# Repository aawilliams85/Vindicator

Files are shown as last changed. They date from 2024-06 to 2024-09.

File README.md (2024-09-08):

SteamVR Saber Staff based on Tundra Labs sample project here: https://github.com/tundra-labs/rp2040_examples
Vanquisher Assembled 2
Vanquisher Parts
Vanquisher Assembled

## Structure
The subfolders in the main directory are as follows:
* VindicatorDriver
    * This contains the driver that tells SteamVR how to use the controller.
    * The subfolder "vindicator" should be copied to "C:\Program Files (x86)\Steam\steamapps\common\SteamVR\drivers"
* VindicatorFirmware
    * This is the RP2040 Arduino code that is programmed into the dev board
* VindicatorInputPCB
    * This is the KiCAD design for the button input board that connects to the RP2040 dev board.
* VindicatorJson
    * This contains example before and after device JSON files to show how to convert to/from the stock Tundra Tracker configuration. 
* VindicatorMechanical
    * This is the FreeCAD model for the 3D printed parts.

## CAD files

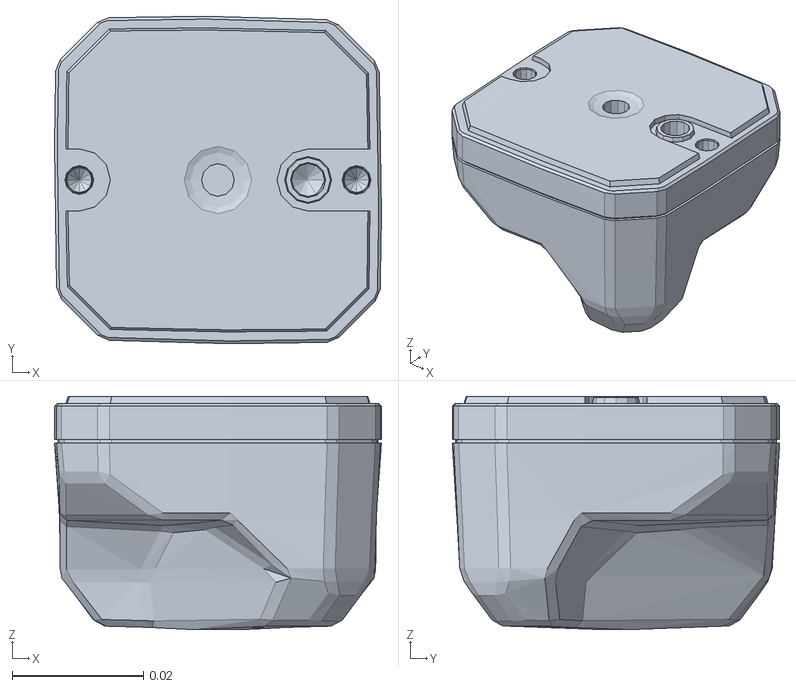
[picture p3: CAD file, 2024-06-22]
VindicatorDriver/vindicator/resources/rendermodels/vindicator/vindicator.obj
0.0499 x 0.05 x 0.0356

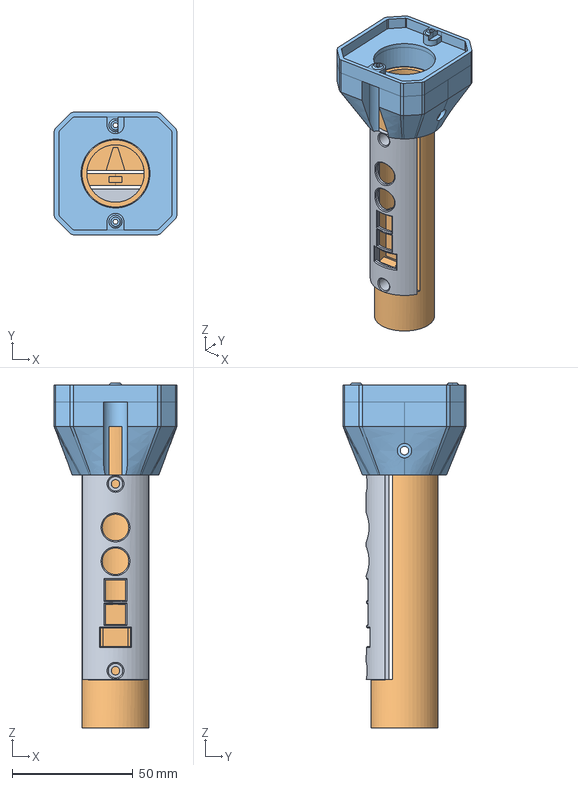
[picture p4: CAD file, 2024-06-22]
VindicatorMechanical/Vindicator.FCStd
51.0 x 51.0 x 143.1 mm
ButtonPanel
Core
TrackerMount

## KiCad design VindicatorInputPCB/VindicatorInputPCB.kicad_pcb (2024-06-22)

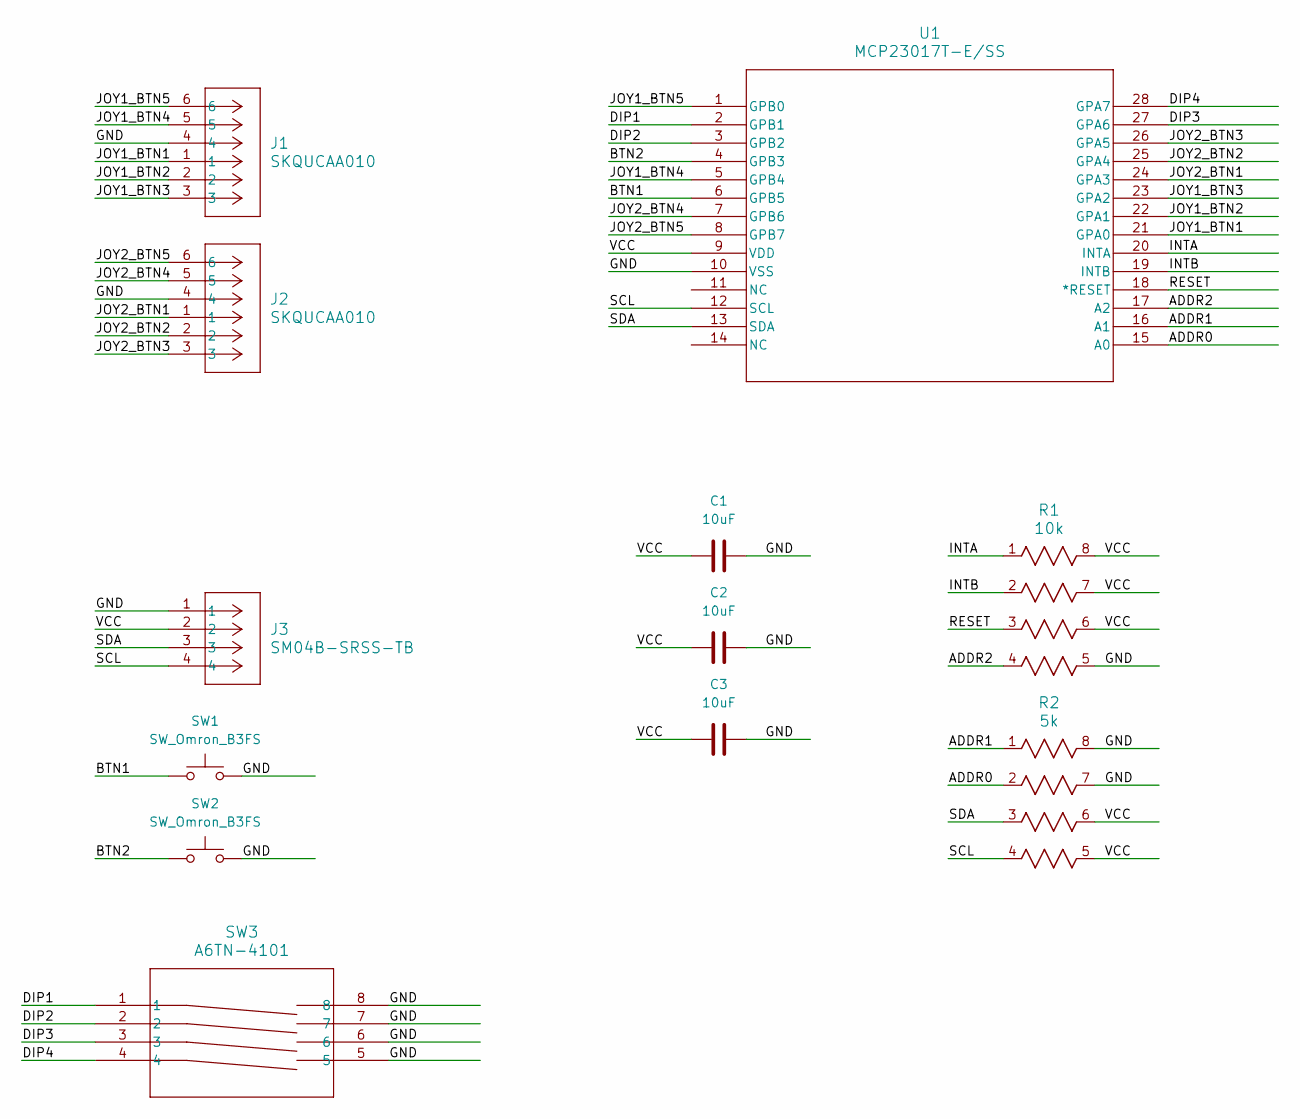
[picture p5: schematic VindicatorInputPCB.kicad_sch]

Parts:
C1, C2, C3: 10uF; C_1206_3216Metric
J1, J2: SKQUCAA010; CONN_SKQUC_ALPS
J3: SM04B-SRSS-TB; CONN_SM04B-SRSS-TB_JST
R1: 10k; EXBV8V_PAN
R2: 5k; EXBV8V_PAN
SW1, SW2: SW_Omron_B3FS; SW_TH_Tactile_Omron_B3F-10xx
SW3: A6TN-4101; SW_A6TN-4101_OMR
U1: MCP23017T-E/SS; SSOP28_MC_MCH

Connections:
/ADDR0: R2.2, U1.15 (A0)
/ADDR1: R2.1, U1.16 (A1)
/ADDR2: R1.4, U1.17 (A2)
/BTN1: SW1.1, U1.6 (GPB5)
/BTN2: SW2.1, U1.4 (GPB3)
/DIP1: SW3.1, U1.2 (GPB1)
/DIP2: SW3.2, U1.3 (GPB2)
/DIP3: SW3.3, U1.27 (GPA6)
/DIP4: SW3.4, U1.28 (GPA7)
/GND: C1.2, C2.2, C3.2, J1.4, J2.4, J3.1, R1.5, R2.7, R2.8, SW1.2, SW2.2, SW3.5, SW3.6, SW3.7, SW3.8, U1.10 (VSS)
/INTA: R1.1, U1.20 (INTA)
/INTB: R1.2, U1.19 (INTB)
/JOY1_BTN1: J1.1, U1.21 (GPA0)
/JOY1_BTN2: J1.2, U1.22 (GPA1)
/JOY1_BTN3: J1.3, U1.23 (GPA2)
/JOY1_BTN4: J1.5, U1.5 (GPB4)
/JOY1_BTN5: J1.6, U1.1 (GPB0)
/JOY2_BTN1: J2.1, U1.24 (GPA3)
/JOY2_BTN2: J2.2, U1.25 (GPA4)
/JOY2_BTN3: J2.3, U1.26 (GPA5)
/JOY2_BTN4: J2.5, U1.7 (GPB6)
/JOY2_BTN5: J2.6, U1.8 (GPB7)
/RESET: R1.3, U1.18 (*RESET)
/SCL: J3.4, R2.4, U1.12 (SCL)
/SDA: J3.3, R2.3, U1.13 (SDA)
/VCC: C1.1, C2.1, C3.1, J3.2, R1.6, R1.7, R1.8, R2.5, R2.6, U1.9 (VDD)

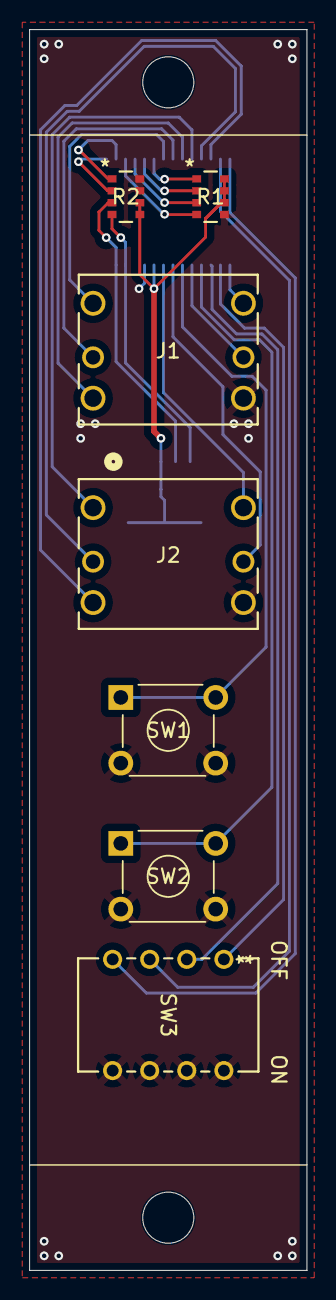
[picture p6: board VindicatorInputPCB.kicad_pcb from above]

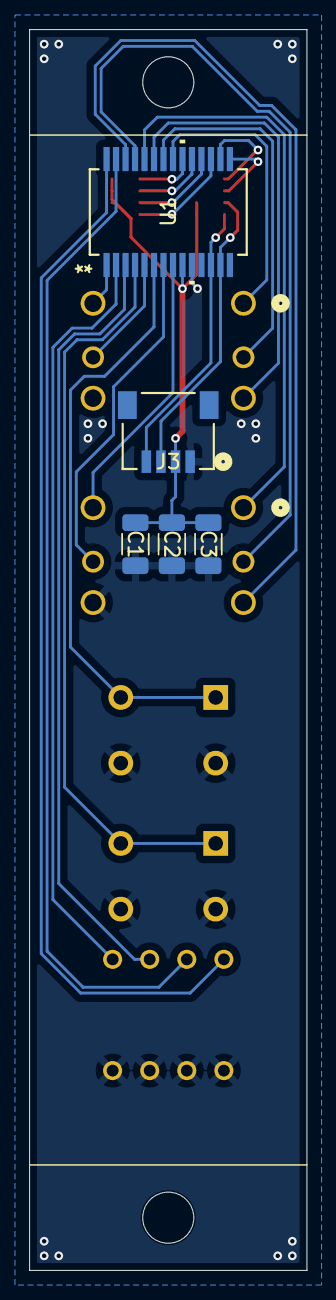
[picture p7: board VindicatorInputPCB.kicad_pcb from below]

Board: 2 copper layers, 19.0 x 85.0 mm, 12 parts (5 on the bottom side), 26 nets.

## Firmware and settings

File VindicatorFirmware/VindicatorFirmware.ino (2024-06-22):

#include <Adafruit_MCP23X17.h>
#include "tundra_mapped_input.h"

#define RP2040_BB_LED           (25)

/////////////////////////////////////////////////////////////////////
// I/O Expander Pinout
/////////////////////////////////////////////////////////////////////
#define JOY1_BTN1_PIN 0    # GPA0 / 21
#define JOY1_BTN2_PIN 1    # GPA1 / 22
#define JOY1_BTN3_PIN 2    # GPA2 / 23
#define JOY1_BTN4_PIN 12   # GPB4 / 5
#define JOY1_BTN5_PIN 8    # GPB0 / 1

#define JOY2_BTN1_PIN 3    # GPA3 / 24
#define JOY2_BTN2_PIN 4    # GPA4 / 25
#define JOY2_BTN3_PIN 5    # GPA5 / 26
#define JOY2_BTN4_PIN 14   # GPB6 / 7
#define JOY2_BTN5_PIN 15   # GPB7 / 8

#define BTN1_PIN 13        # GPB5 / 6
#define BTN2_PIN 11        # GPB3 / 4

#define DIP1_PIN 9         # GPB1 / 2
#define DIP2_PIN 10        # GPB2 / 3
#define DIP3_PIN 6         # GPA6 / 27
#define DIP4_PIN 7         # GPA7 / 28

Adafruit_MCP23X17 mcp;
/////////////////////////////////////////////////////////////////////


// Create TMI object to communicate with Tundra Tracker
TMI tundra_tracker;
void csn_irq( uint gpio, uint32_t event_mask );  // Chip select IRQ must be top level so let's make one and connect it later in setup

// Use packed structs to define the inputs for your controller
// First we make a struct of buttons
typedef struct __attribute__( ( packed, aligned( 1 ) ) )
{

}
controller_buttons_t;

// Make a top level struct that packs the button data along with the rest of the controller analog values
typedef struct __attribute__( ( packed, aligned( 1 ) ) )
{
  uint16_t      buttons         : 16;
} 
controller_data_t;

// declare the controller struct for use
controller_data_t controller_data;

uint16_t input_data = 0; // I/O data from this scan
uint16_t input_data_last = 0; // I/O data from the previous scan
uint32_t interval_gpio = 25; // Time interval to check GPIO for new data (ms)
uint32_t next_time_gpio = 0;

uint32_t interval_send = 1000; // Time interval to send data to tracker, even if no data has changed (ms)
uint32_t next_time_send = 0;
bool send_requested = false;
bool led_state = false;

void setup() {
  
  pinMode(RP2040_BB_LED, OUTPUT);

  // init the communication to Tundra Tracker, setup the CS irq callback (this has to be at Top level in arduino it seems)
  tundra_tracker.init( );
  gpio_set_irq_enabled_with_callback( tundra_tracker.get_cs_pin(), GPIO_IRQ_EDGE_RISE | GPIO_IRQ_EDGE_FALL, true, &csn_irq );

  Serial.begin();
  delay(1000);
  //while(!Serial){} //Debug operation only
  while (!mcp.begin_I2C(0x20, &Wire1)){
    Serial.println("Waiting for i2c");
    delay(250);
  }
  for (int i = 0; i < 16; i++){
    mcp.pinMode(i, INPUT_PULLUP);
  }
}


// the loop function runs over and over again forever
void loop() {
  if (millis() > next_time_gpio) {
    input_data = ~mcp.readGPIOAB();
    //Serial.println(input_data);
    next_time_gpio = millis() + interval_gpio;
  }

  if ((millis() > next_time_send)||(input_data != input_data_last)) {
    controller_data.buttons = input_data;
    send_requested = true;
    next_time_send = millis() + interval_send;
  }

  if (send_requested) {
    if (tundra_tracker.data_ready()){
      tundra_tracker.send_data(&controller_data, sizeof(controller_data));
      tundra_tracker.handle_rx_data();
      digitalWrite(RP2040_BB_LED, led_state ^= true);
      input_data_last = input_data;
      send_requested = false;
    }
  }
}

// Callback for SPI Chipselect, just connect in the tmi irq function
void csn_irq( uint gpio, uint32_t event_mask )
{
  tundra_tracker.csn_irq( gpio, event_mask );
}

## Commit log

2024-06-22 Initial rev
    [Vindicator.FCStd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]
2024-06-22 Fixed I/O getting stuck
    [VindicatorFirmware.ino]
